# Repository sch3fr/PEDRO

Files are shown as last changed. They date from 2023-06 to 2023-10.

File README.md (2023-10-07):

# Project P.E.D.R.O.
Pedro (Personal Emotional Display of Robust Obstruction) is an arduino based
LED mask.
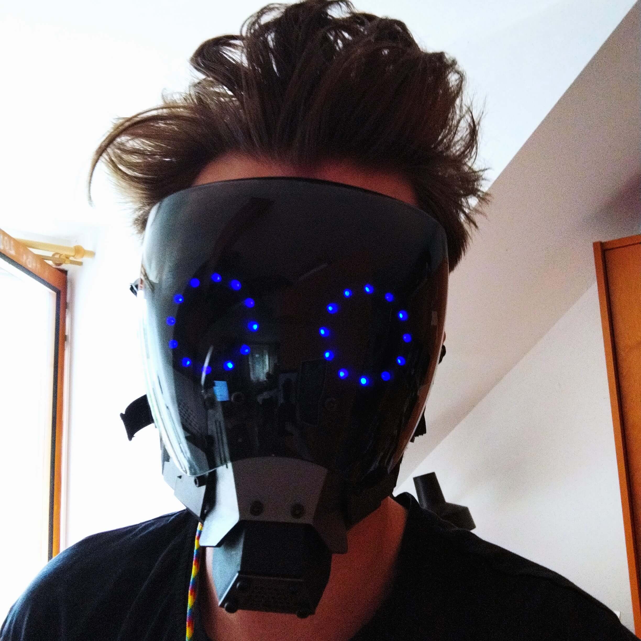
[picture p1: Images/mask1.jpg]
Completed mask
    
## How it works
There are two sets of charlieplexed LEDs inside the mask visor. The leds are connected to a control box (that I mounted 
to my belt using zip ties). Inside of the control box there is Arduino Nano, controling the whole thing. On the front of
the control box there are 4 buttons for changing the LED animatins. The mask is powered by powerbank I shoved into my 
pocket.
## Versions
Due to time constrains, I wasnt't able to finish the original plan of making
a Watch_Dogs 2 Wrench-style LED matrix, since I don't know much about electronics
and the event I wanted to attend with a mask was in September. <br>
That means that the first version of this mask is much simpler, with two charlieplexed LED circles.<br>
I still want to make rev 2 with fully animated LED matrix display, but that will have to wait for later™️.
## Version 1
### Bill of Materials
- 24* LEDs, ⌀ 3mm
- 4* 330 Ohm resistors
- 1* 1K Ohm resistor
- 1* Arduino Nano
- 4 buttons; leftover mechanical keyboard switchies are used in my case with 4 keycyps
- 1* Paintball/airsoft style mask. [I used this one](https://www.aliexpress.com/item/1005005392812734.html?spm=a2g0o.order_list.order_list_main.63.6b571802MzwtKa)
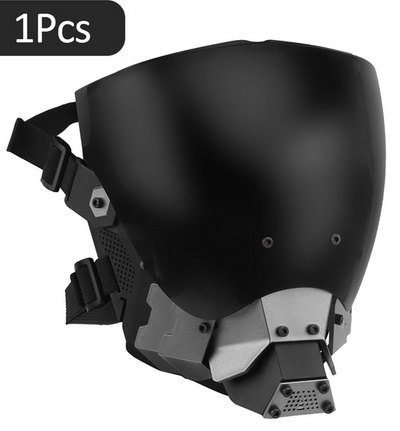
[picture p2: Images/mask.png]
Mask I used
    
- 1* 3D printed eyepiece
- 1* 3D printed control box
- a length some wire
- 2 longer or 4 shorter zip ties
- (optional) 1 or 2 LED jigs
- (optional) 1 m of paracord

### Build Guide
1. Print the LED jigs, the eyepiece and the control box pieces
    - files ledJIG.stl, eyePiece.stl, caseTop.stl and caseBottom.stl
2. Populate the LED jigs with LEDs
3. Start wiring the LEDs according to a diagram in /Schematics/
    - it should look similar to this
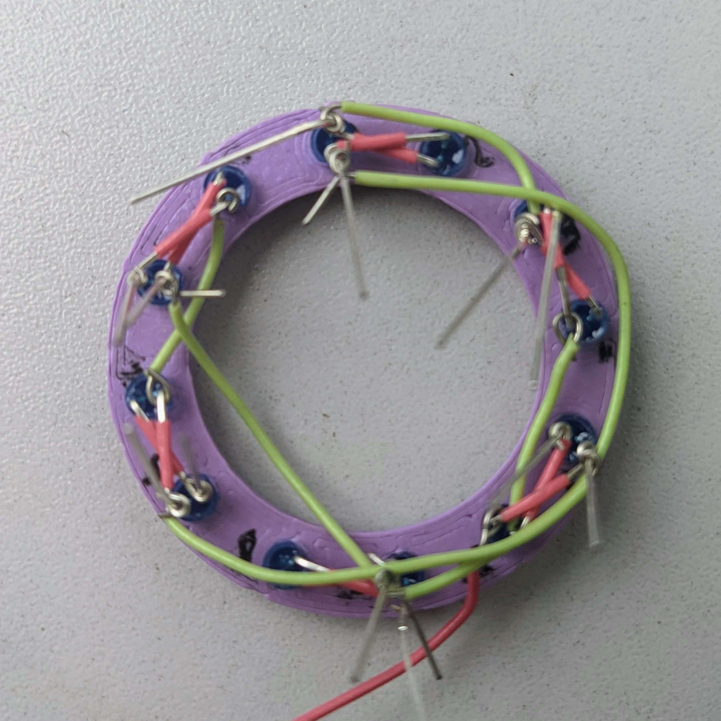
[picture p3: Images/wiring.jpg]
Photo of leds wired
    
4. Once you have the LED circles wired and tested, cut 4 1m long pieces of wire, make twisted pairs
    - optional - route the cables through a paracord sleeve to make it look better
5. Populate the top of the control box with switches, wire them to the Arduino
    - connect 1K Ohm resistor to arduino ground, then one leg of buttons to pins 6, 5, 4, 3, and all of the other legs 
    to the resistor
6. Connect the twisted wires to the Arduino
    - pins 12, 11, 10 and 9
7. Route the cable to the mask
8. Take out the LED circles from the jigs and insert them to the eyepiece
    - Insert LED circles to the eyePiece in a way that mimics the face of a clock (LED 12 at the top, LED 6 at the 
    bottom, etc.), then screw it to the mask
9. Screw the eyepiece into the mask, there are some holes that I was able to use without modifying anything
10. Add 330 Ohm resistor to the ends of the cable wires
11. Connect the wires to eye LEDs, make sure to connect it in the right order
    - refer to the wiring diagram
12. Flash the firmware file in /Arduino/charlieplexing
13. Enjoy your mask

If you have any questions, feel free to reach out to me.

I'll make sure to post more images soon. In the meantime, you can read more on projects website [here](https://sch3fr.github.io/pages/Projects/pedro.html)
### Demo
Demo of mask 1
## To do
- [x] Design circuit
- [x] Write software
- [x] Design parts for 3D printing
- [x] Print it
- [x] Wire it
- [x] Build it
- [x] Share circuit plan
- [ ] Create more diagrams for easier comprehension

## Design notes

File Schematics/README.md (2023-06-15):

# Notes
I'm using Arduino Mega in the schematics, as it was the only Arduino available
in TinyCAD. I used Arduino Nano in final project. It shouldn't matter anyway, as 
the pins used work the same way on Mega, Uno and Nano. In case something does go 
wrong, you can always customize the charlieplexing.ino file.<br>
Check out TinyCAD [here.](https://www.tinycad.net/) <br>
I used [this](http://www.multiwingspan.co.uk/arduino.php?page=charlie) guide to 
charlieplexing while designing the circuit.

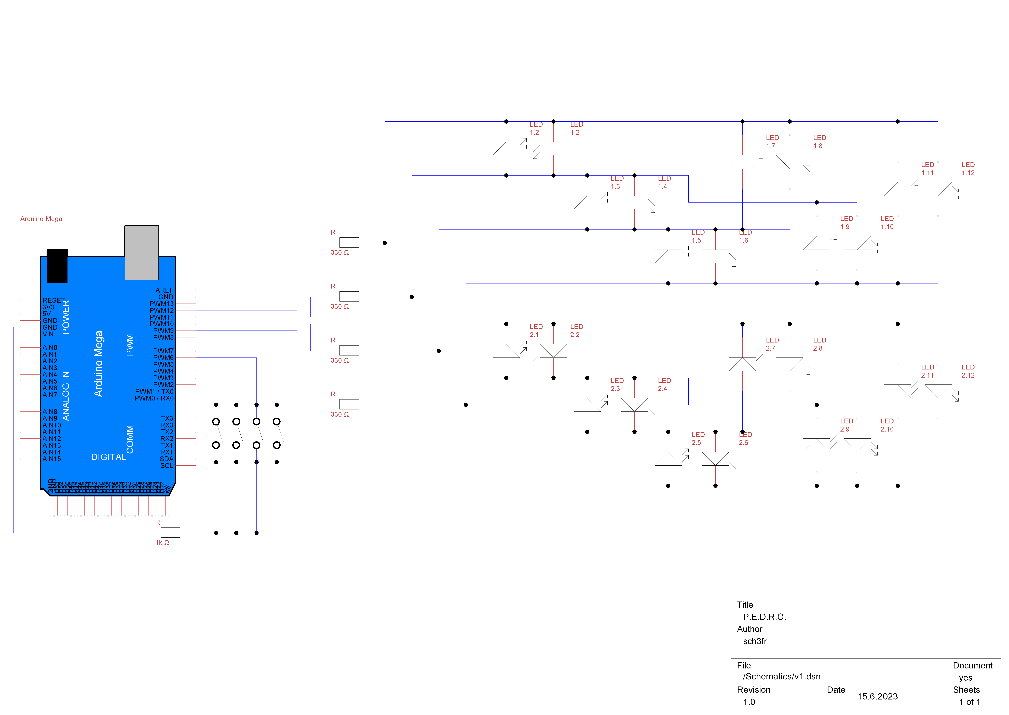
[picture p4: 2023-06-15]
Schematics/v1.png

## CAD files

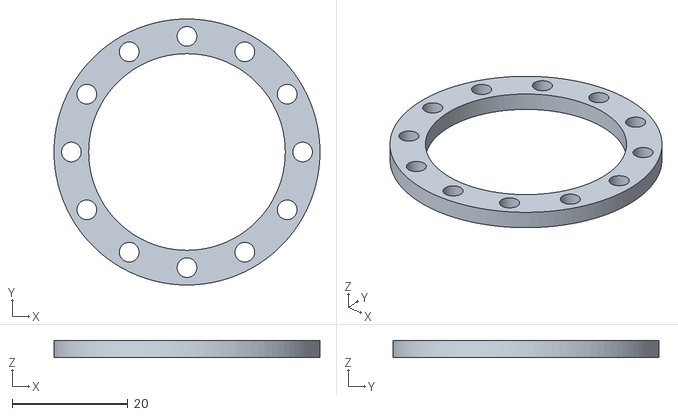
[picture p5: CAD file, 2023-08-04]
3D files/ledJIG.stl
46.0 x 46.0 x 3.00

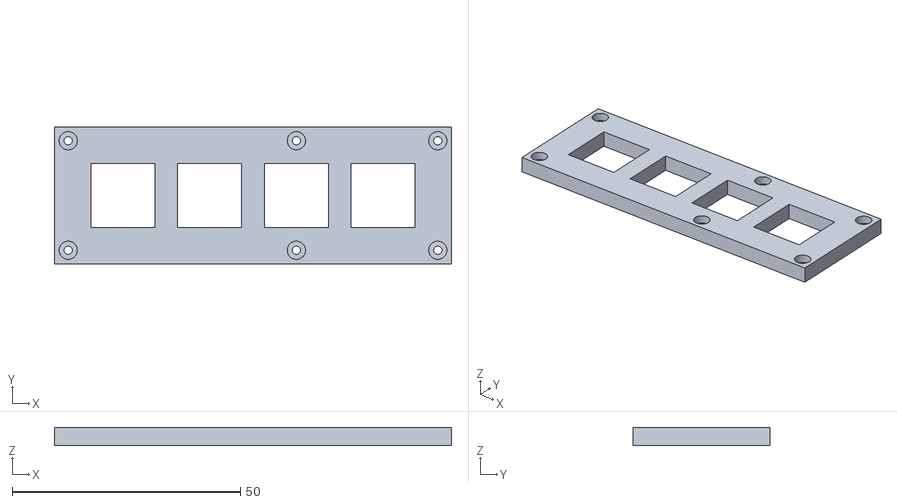
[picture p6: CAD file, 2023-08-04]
3D files/tinkercad/caseTop.stl
87.0 x 30.0 x 4.00

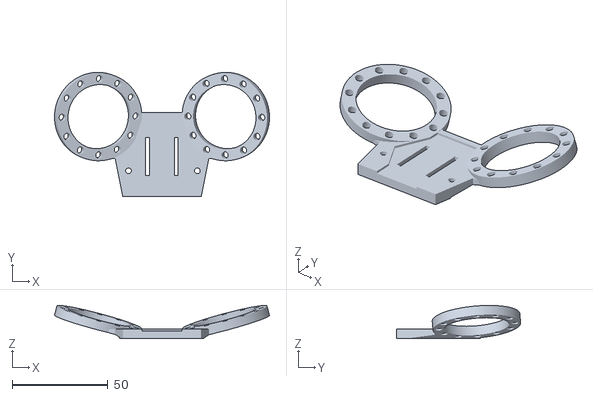
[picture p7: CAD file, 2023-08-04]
3D files/tinkercad/eyePiece.stl
112.4 x 65.0 x 17.3

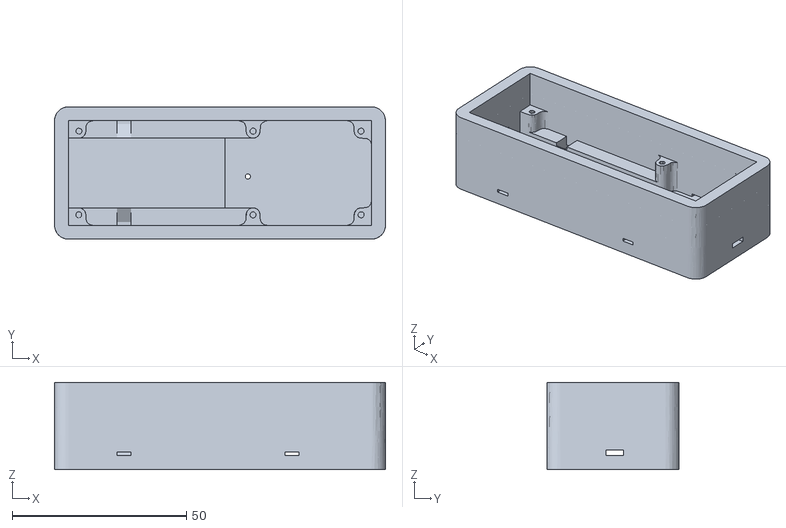
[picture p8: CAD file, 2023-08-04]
3D files/tinkercad/caseBottom.stl
95.0 x 38.0 x 25.0

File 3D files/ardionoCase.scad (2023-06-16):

borderHeight = 25;
sizeX = 85;
sizeY = 24;

details=20; //change to 100 for best render, lower for fast render

//translate([2,2,0])square([sizeX, sizeY]);

module walls(){
    //rounded corners
    translate([2,2,0])cylinder(borderHeight, 2, 2, $fn=details);
    translate([2,sizeY+2,0])cylinder(borderHeight, 2, 2, $fn=details);
    translate([sizeX+2,2,0])cylinder(borderHeight, 2, 2, $fn=details);
    translate([sizeX+2,sizeY+2,0])cylinder(borderHeight, 2, 2, $fn=details);

    //actual walls
    translate([2,0,0])cube([sizeX,4,borderHeight]);
    translate([0,sizeY,0])translate([2,0,0])cube([sizeX,4,borderHeight]);
    translate([0,2,0])cube([4,sizeY,borderHeight]);
    translate([sizeX,2,0])cube([4,sizeY,borderHeight]);
    
    //floor
    translate([2,2,0])cube([sizeX,sizeY,2]);
    //floor thickener
    translate([sizeX-sizeX/2+6,2,0])cube([sizeX/2-6,sizeY,4]); //+- 6mm compensates for the size of arudino, which is larger than sizeX/2
}

difference() {
    walls();
    translate([2,2,14])cube([sizeX+2,sizeY,4]);//plate slide-in hole
    
    //microUSB connector hole
    translate([0,10,5])cube([10,8,3]);
    #translate([0,8,3])cube([3,12,7]);
    
}
//#translate([78,-64,2])import("C:/Users/sch3f/Desktop/arduinoNanoModel.stl");

module switches() {
    difference(){
        cube([87,23.5,3.8]); //plate
        translate([7,4.75,0])cube([14,14,6]); //switch hole1
        translate([26,4.75,0])cube([14,14,6]); //switch hole2
        translate([45,4.75,0])cube([14,14,6]); //switch hole3
        translate([64,4.75,0])cube([14,14,6]); //switch hole4
    }
}

translate([0,50,0])switches();

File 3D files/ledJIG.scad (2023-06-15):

external_radius = 20; // 23 reccomended if you want to go larger
internal_radius = 14; // 17 reccomended if you want to go larger
LED_radius = 1.7; //1.7 is the LED radius, I found that the 1.7 works great for my print settings and LEDs I have at hand

linear_extrude(3){

difference(){
    circle(external_radius, $fn=100);
    circle(internal_radius, $fn=100); //or 17 for larger internal diameter
    for (angle=[0:30:360]) 
        {
        rotate([0, 0, angle]) translate([17, 0, 0]) circle(LED_radius, $fn=100);
        }
    }
}

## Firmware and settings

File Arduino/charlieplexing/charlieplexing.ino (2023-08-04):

int LED_A = 12; //connects to LED 1
int LED_B = 11; //connects to LED 1
int LED_C = 10; //connects to LED 3
int LED_D = 9; //connects to LED 6

// Pins connected to the buttons
int button1Pin = 6;
int button2Pin = 5;
int button3Pin = 4;
int button4Pin = 3;

// Variables to store the button states
int buttonState1 = 0;
int buttonState2 = 0;
int buttonState3 = 0;
int buttonState4 = 0;

// Flags to control the functions
bool function1Running = false;
bool function2Running = false;
bool function3Running = false;
bool function4Running = false;

// Pull up pins
int pullup1 = 8;
int pullup2 = 7;
int pullup3 = 2;
int pullup4 = 1;

void setup() {
  pinMode(button1Pin, INPUT_PULLUP);
  pinMode(button2Pin, INPUT_PULLUP);
  pinMode(button3Pin, INPUT_PULLUP);
  pinMode(button4Pin, INPUT_PULLUP);

  pinMode(pullup1, INPUT_PULLUP);
  pinMode(pullup2, INPUT_PULLUP);
  pinMode(pullup3, INPUT_PULLUP);
  pinMode(pullup4, INPUT_PULLUP);  
}

void loop() {
  buttonState1 = digitalRead(button1Pin);
  buttonState2 = digitalRead(button2Pin);
  buttonState3 = digitalRead(button3Pin);
  buttonState4 = digitalRead(button4Pin);

  if (buttonState1 == LOW && !function1Running) {
    stopAllFunctions();
    function1Running = true;
    animationFull();
  }

  if (buttonState2 == LOW && !function2Running) {
    stopAllFunctions();
    function2Running = true;
    animationUpper();
  }

  if (buttonState3 == LOW && !function3Running) {
    stopAllFunctions();
    function3Running = true;
    animationLower();
  }

  if (buttonState4 == LOW && !function4Running) {
    stopAllFunctions();
    function4Running = true;
    animationLoading();
  }
}

void animationFull() {
  while (function1Running) {
    for (int i = 1; i < 13; i++)
    {
      light_led(i);
      delay(1);
    }
    buttonState2 = digitalRead(button2Pin);
    buttonState3 = digitalRead(button3Pin);
    buttonState4 = digitalRead(button4Pin);

    if (buttonState2 == LOW || buttonState3 == LOW || buttonState4 == LOW) {
      function1Running = false;
    }
  }
}

void animationUpper() {
  while (function2Running) { // the LEDs are assembled and numbered like numbers on a clock
    light_led(10);           // that's why there is this odd numbering for this function and
    delay(1);                // the animationLower() funtion
    light_led(11);
    delay(1);
    light_led(12);
    delay(1);
    light_led(1);
    delay(1);
    light_led(2);
    delay(1);

    buttonState1 = digitalRead(button1Pin);
    buttonState3 = digitalRead(button3Pin);
    buttonState4 = digitalRead(button4Pin);

    if (buttonState1 == LOW || buttonState3 == LOW || buttonState4 == LOW) {
      function2Running = false;
    }
  }
}

void animationLower() {
  while (function3Running) {
    light_led(4);
    delay(1);
    light_led(5);
    delay(1);
    light_led(6);
    delay(1);
    light_led(7);
    delay(1);
    light_led(8);
    delay(1);

    buttonState1 = digitalRead(button1Pin);
    buttonState2 = digitalRead(button2Pin);
    buttonState4 = digitalRead(button4Pin);

    if (buttonState1 == LOW || buttonState2 == LOW || buttonState4 == LOW) {
      function3Running = false;
    }
  }
}

void animationLoading() {
  while (function4Running) {
    for (int i = 1; i < 13; i++)
    {
      light_led(i);
      delay(35); //original 35
    }

    buttonState1 = digitalRead(button1Pin);
    buttonState2 = digitalRead(button2Pin);
    buttonState3 = digitalRead(button3Pin);

    if (buttonState1 == LOW || buttonState2 == LOW || buttonState3 == LOW) {
      function4Running = false;
    }
  }
}

void stopAllFunctions() {
  function1Running = false;
  function2Running = false;
  function3Running = false;
  function4Running = false;
}

void reset_pins()
{
  pinMode(LED_A, INPUT);
  pinMode(LED_B, INPUT);
  pinMode(LED_C, INPUT);
  pinMode(LED_D, INPUT);
  digitalWrite(LED_A, LOW);
  digitalWrite(LED_B, LOW);
  digitalWrite(LED_C, LOW);
  digitalWrite(LED_D, LOW);
}

void set_pins(int high_pin, int low_pin)
{
  reset_pins();
  pinMode(high_pin, OUTPUT);
  pinMode(low_pin, OUTPUT);
  digitalWrite(high_pin, HIGH);
  digitalWrite(low_pin, LOW);
}

void light_led(int led_num) {
  switch (led_num)
  {
    case 1:
      set_pins(LED_B, LED_A);
      break;
    case 2:
      set_pins(LED_A, LED_B);
      break;
    case 3:
      set_pins(LED_C, LED_B);
      break;
    case 4:
      set_pins(LED_B, LED_C);
      break;
    case 5:
      set_pins(LED_D, LED_C);
      break;
    case 6:
      set_pins(LED_C, LED_D);
      break;
    case 7:
      set_pins(LED_C, LED_A);
      break;
    case 8:
      set_pins(LED_A, LED_C);
      break;
    case 9:
      set_pins(LED_D, LED_B);
      break;
    case 10:
      set_pins(LED_B, LED_D);
      break;
    case 11:
      set_pins(LED_D, LED_A);
      break;
    case 12:
      set_pins(LED_A, LED_D);
      break;
  }
}

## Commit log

2023-06-13 added first arduino sketch
2023-06-13 arduino now responds to buttons
2023-06-15 changed pin numbers for arduino nano
2023-06-15 added schematics
    [ledJIG.scad, v1.dsn]
2023-06-15 small fixes and tweaks
    [v1.dsn]
2023-06-16 started working on encousure
    [ardionoCase.scad]
2023-06-16 changed button pins due to physical clearance
    [charlieplexing.ino]
2023-08-04 documentation and small fixes
    [caseBottom.stl, caseTop.stl, ledJIG.stl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]
2023-10-07 readme update with better build guide
    [eyePiece.stl]
